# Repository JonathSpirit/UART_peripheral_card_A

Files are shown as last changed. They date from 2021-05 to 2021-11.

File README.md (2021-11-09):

# UART_peripheral_card_A

Copyright (C) 2021 Guillaume Guillet\
Licensed under CERN-OHL-W v2 or later

<table border="0px">
<tr>
<td>
This source describes Open Hardware and is licensed under the CERN-OHL-W v2 or later.
</td>
</tr>
<tr>
<td>
You may redistribute and modify this documentation and make products
using it under the terms of the CERN-OHL-W v2 (https:/cern.ch/cern-ohl).
This documentation is distributed WITHOUT ANY EXPRESS OR IMPLIED
WARRANTY, INCLUDING OF MERCHANTABILITY, SATISFACTORY QUALITY
AND FITNESS FOR A PARTICULAR PURPOSE. Please see the CERN-OHL-W v2
for applicable conditions.
</td>
</tr>
</table>

Made with [Kicad](https://kicad.org/)

## Description
A UART peripheral card compatible with [PP1 standard](https://github.com/JonathSpirit/GComputer_standard).
This is a homemade without any microcontroller UART board that can transmit and receive in fixed 9600 baud rate and full-duplex.

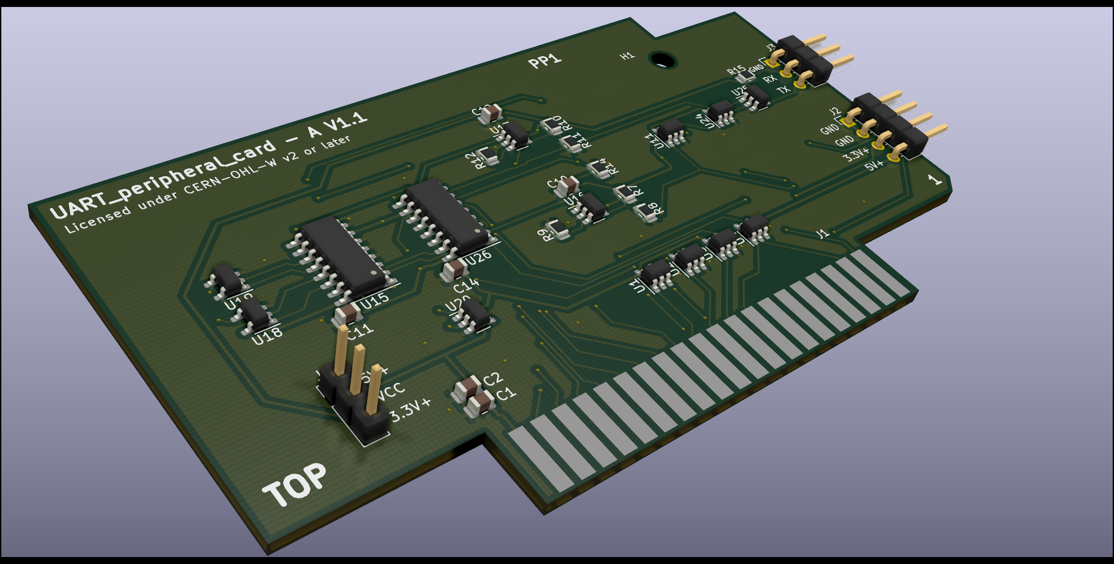
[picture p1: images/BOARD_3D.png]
BOARD_3D

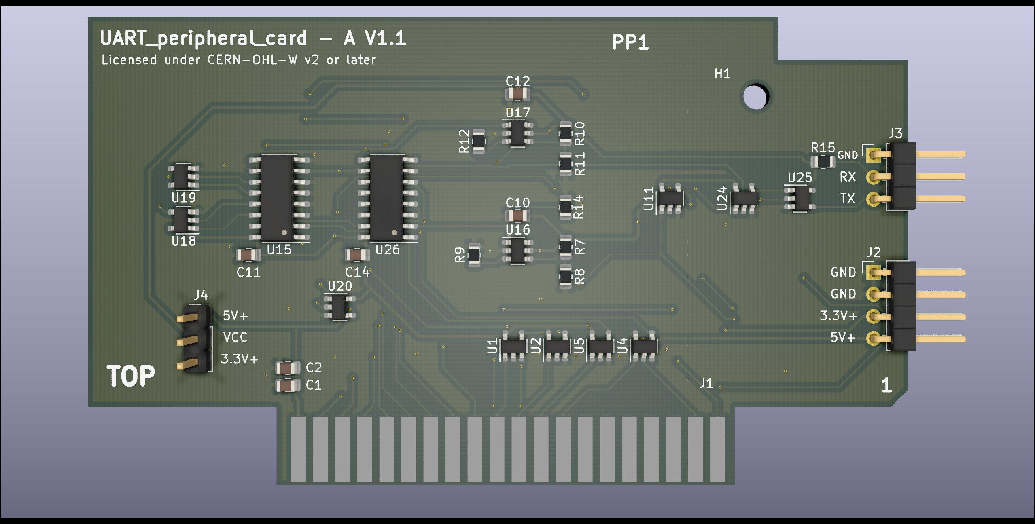
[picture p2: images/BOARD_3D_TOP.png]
BOARD_3D_TOP
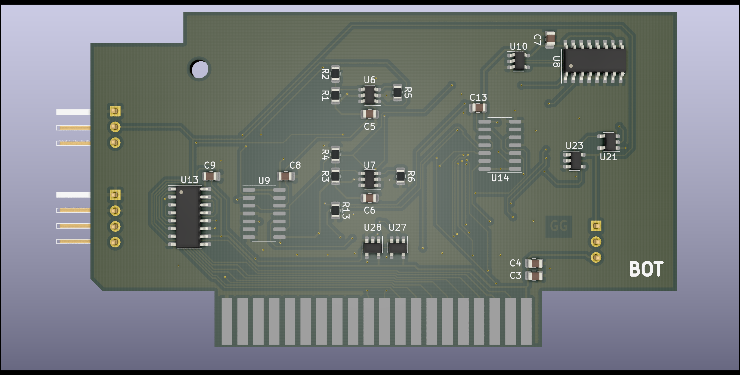
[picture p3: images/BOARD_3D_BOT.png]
BOARD_3D_BOT
 

## Stats





\
\
\


## Main features

- Follow the [PP1](https://github.com/JonathSpirit/GComputer_standard) standard.

- Fixed 9600 baud rate.

- Full duplex.

- 1 byte receive/transmit buffer.

- Compatible CMOS/TTL logic level.

## Documents
[Schematics (.pdf)](documents/UART_peripheral_card_A_schematics.pdf)

[Materials (.pdf)](documents/UART_peripheral_card_A_materials.pdf)

## Contributing / Questions
Please see [Contributing file](CONTRIBUTING.md)

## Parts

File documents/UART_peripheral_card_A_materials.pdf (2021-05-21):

1

UART_peripheral_card_A_materials.fods

UART_peripheral_card | A V1.1
Author : Guillaume Guillet | Revision 1 | Licensed under CERN-OHL-W v2 or later
Type | Value | Q | References | Package | Manufacturer | Store | Store ID | Unit price* | Price
C | 10nF | 6 | C7 to C9, C11, C13, C14 | C_0805_2012Metric | KEMET | Mouser | 80-C0805C103J5R | 0.092 | 0.552
| 1uF | 2 | C1, C3 | C_0805_2012Metric | KEMET | Mouser | 80-C0805C105K3R | 0.119 | 0.238
| 100nF | 6 | C2, C4 to C6, C10, C12 | C_0805_2012Metric | KEMET | Mouser | 80-C0805C104M3R | 0.092 | 0.552
U | LTC6990CS6 | 2 | U7, U16 | SOT-23-6 | Analog Devices | Mouser | 584-LTC6990CS6TRMPBF | 3.68 | 7.36
| LTC6994-1 | 2 | U6, U17 | SOT-23-6 | Analog Devices | Mouser | 584-C6994IS6-1TRMPBF | 3.68 | 7.36
| CD74AC161M | 2 | U8, U15 | SOP-16_3.9x9.9mm_P1.27mm | Texas Instruments | Mouser | 595-CD74AC161M | 0.751 | 1.502
| 74HCT107 | 2 | U9, U14 | SO-14_3.9x8.65mm_P1.27mm | Nexperia | Mouser | 771-HCT107D653 | 0.558 | 1.116
| 74AHC1G125 | 2 | U27, U28 | SOT-23-5 | Texas Instruments | Mouser | 595-SN74AHC1G125DBVR | 0.3 | 0.6
| 74AHC1G04 | 1 | U23 | SOT-23-5 | Texas Instruments | Mouser | 595-SN74AHC1G04DBVR | 0.274 | 0.274
| 74AHC1G08 | 1 | U24 | SOT-23-5 | Texas Instruments | Mouser | 595-SN74AHC1G08DBVR | 0.274 | 0.274
| 74AHC1G32 | 5 | U11, U18, U19, U21, U25 | SOT-23-5 | Texas Instruments | Mouser | 595-SN74AHC1G32DBVR | 0.274 | 1.37
| 74AHC1G00 | 6 | U1, U2, U4, U5, U10, U20 | SOT-23-5 | Texas Instruments | Mouser | 595-SN74AHC1G00DBVR | 0.3 | 1.8
| 74AHC595 | 1 | U13 | SOIC-16_3.9x9.9mm_P1.27mm | Texas Instruments | Mouser | 595-SN74AHC595DRE4 | 0.485 | 0.485
| 74HC165 | 1 | U26 | SOIC-16_3.9x9.9mm_P1.27mm | Texas Instruments | Mouser | 595-SN74HC165DRG4 | 0.403 | 0.403
R | 102k | 2 | R1, R11 | R_0805_2012Metric | Bourns | Mouser | 652-CR0805FX-1023ELF | 0.092 | 0.184
| 1M | 2 | R3, R7 | R_0805_2012Metric | Bourns | Mouser | 652-CR0805FX-1004ELF | 0.092 | 0.184
| 562k | 1 | R12 | R_0805_2012Metric | Bourns | Mouser | 652-CR0805FX-5623ELF | 0.092 | 0.092
| 10k | 3 | R13 to R15 | R_0805_2012Metric | Bourns | Mouser | 652-CR0805-JW-103ELF | 0.092 | 0.276
| 976k | 2 | R2, R10 | R_0805_2012Metric | Bourns | Mouser | 652-CR0805FX-9763ELF | 0.092 | 0.184
| 280k | 2 | R4, R8 | R_0805_2012Metric | Bourns | Mouser | 652-CR0805FX-2803ELF | 0.092 | 0.184
| 243k | 1 | R5 | R_0805_2012Metric | Bourns | Mouser | 652-CR0805FX-2433ELF | 0.092 | 0.092
| 649k | 2 | R6, R9 | R_0805_2012Metric | Vishay / Dale | Mouser | 71-CRCW0805649KFKEA | 0.092 | 0.184
J | Conn_01x04_Male_H | 1 | J2 | PinHeader_1x04_P2.54mm_Horizontal | TE connectivity | Mouser | 571-826947-4 | 0.384 | 0.384
| Conn_01x03_Male_H | 1 | J3 | PinHeader_1x03_P2.54mm_Horizontal | TE connectivity | Mouser | 571-826947-3 | 0.356 | 0.356
| Conn_01x03_Male_V | 1 | J4 | PinHeader_1x03_P2.54mm_Vertical | TE connectivity | Mouser | 571-4-103321-5 | 0.211 | 0.211
| Jumper | 1 | - | Jumper | Harwin | Mouser | 855-M7582-05 | 0.183 | 0.183
- | PCB_AV1.1 | 1 | - | - | G.Guillet | - | | | 0
Total price : | 26.4
*Depend of the quantity | Price is in CHF

# Project :

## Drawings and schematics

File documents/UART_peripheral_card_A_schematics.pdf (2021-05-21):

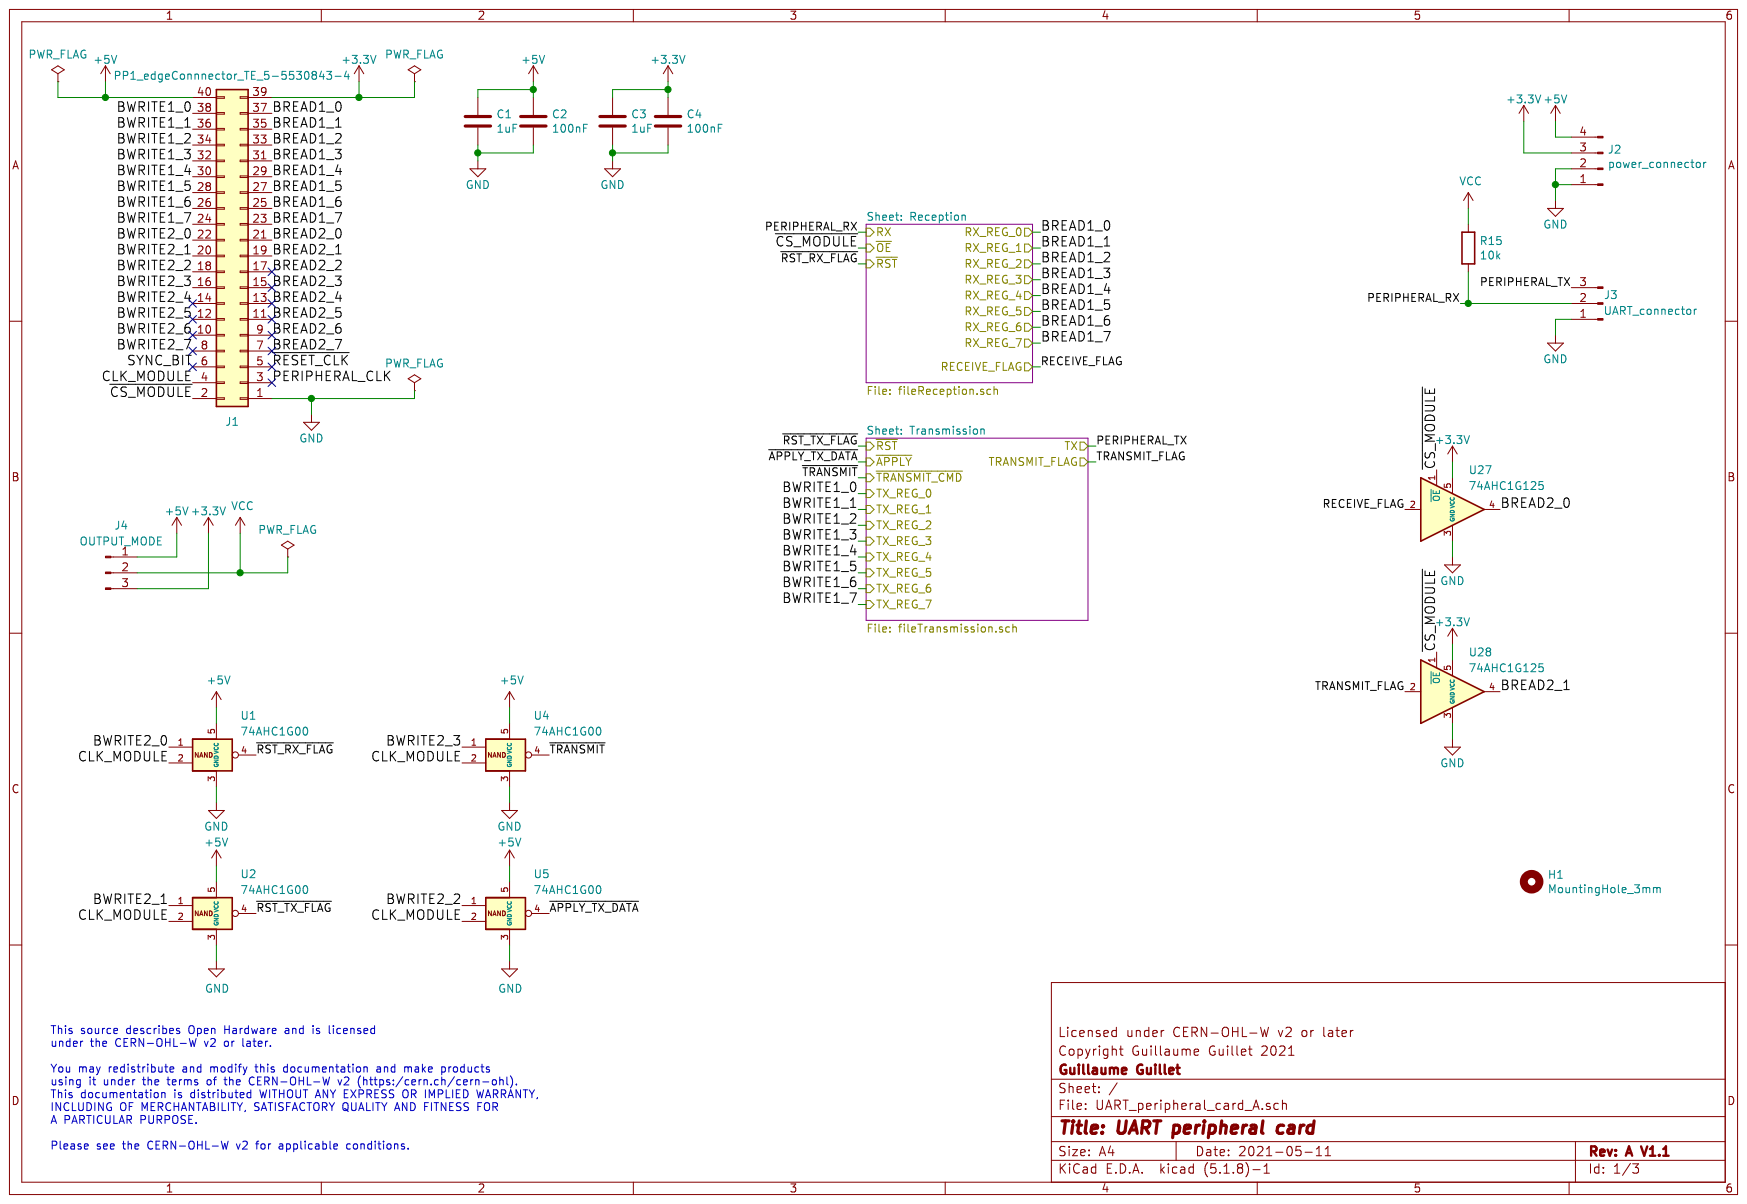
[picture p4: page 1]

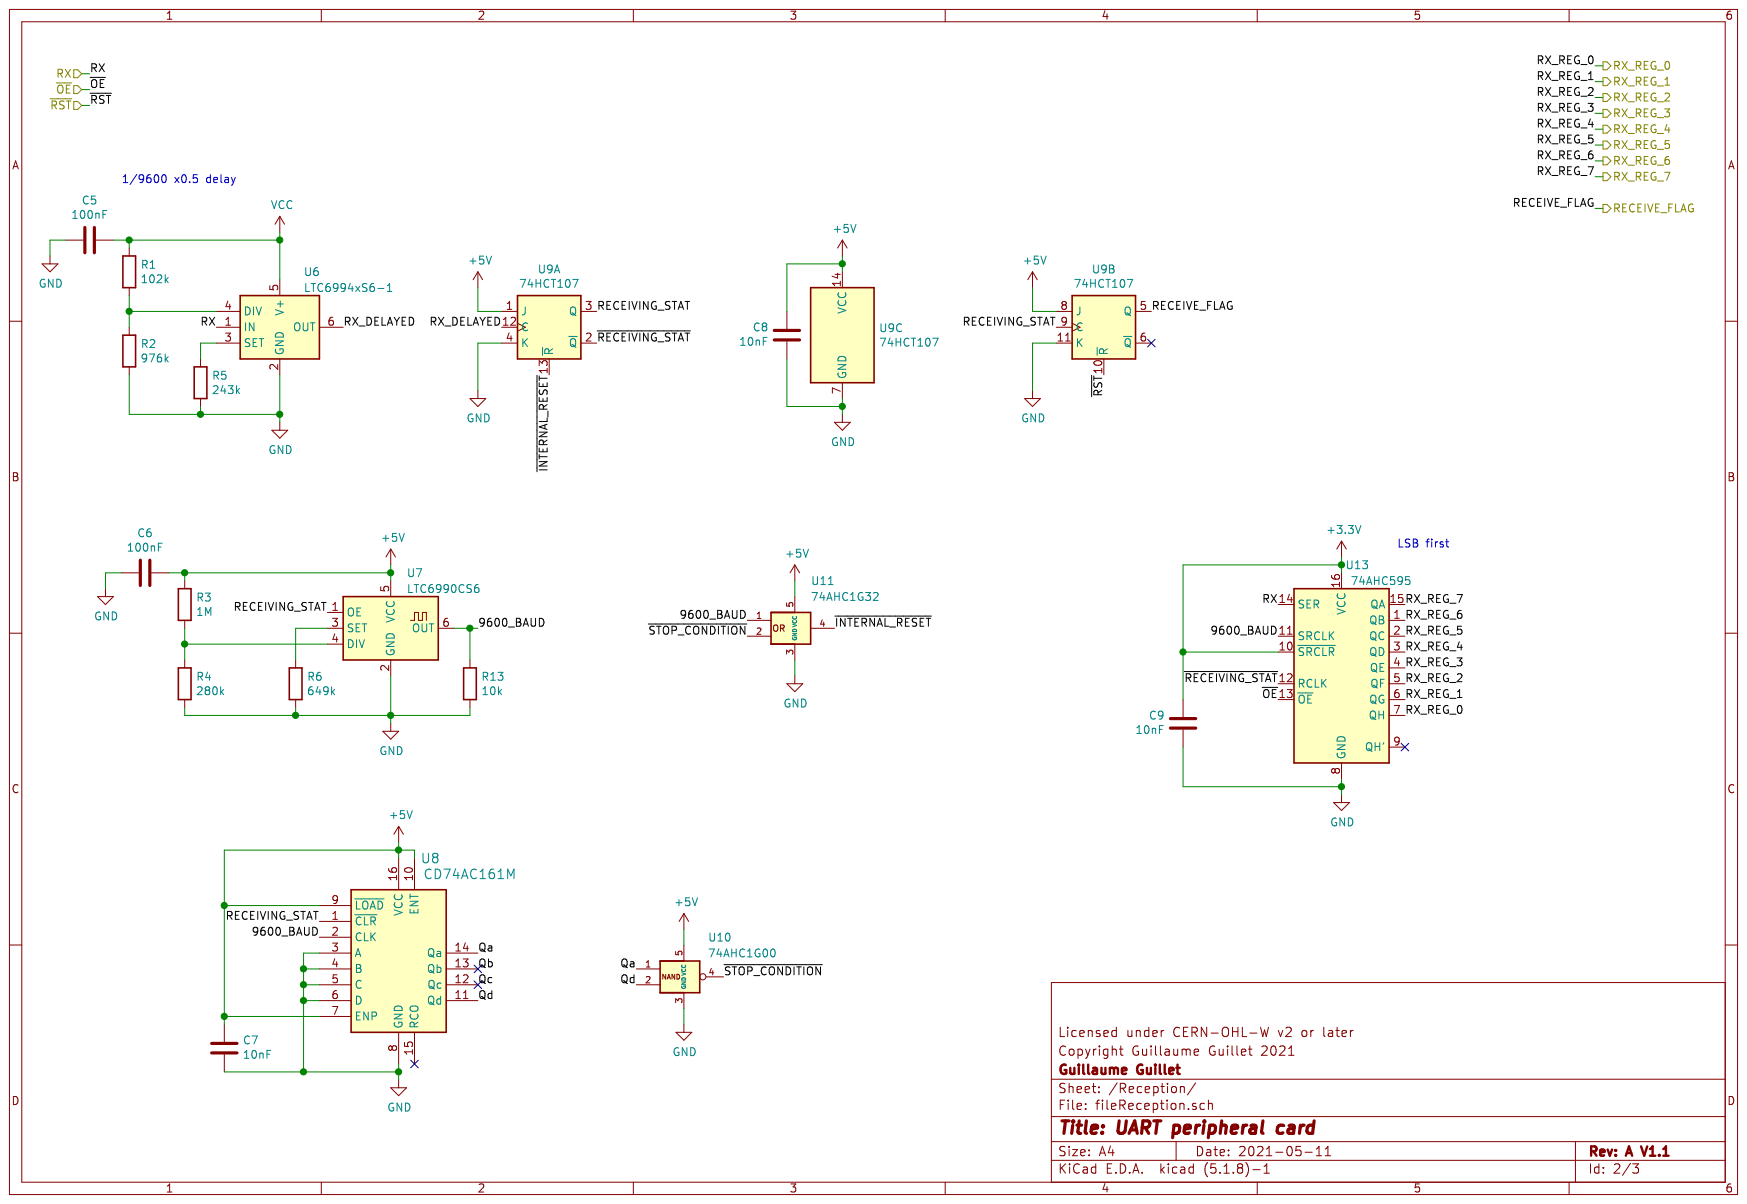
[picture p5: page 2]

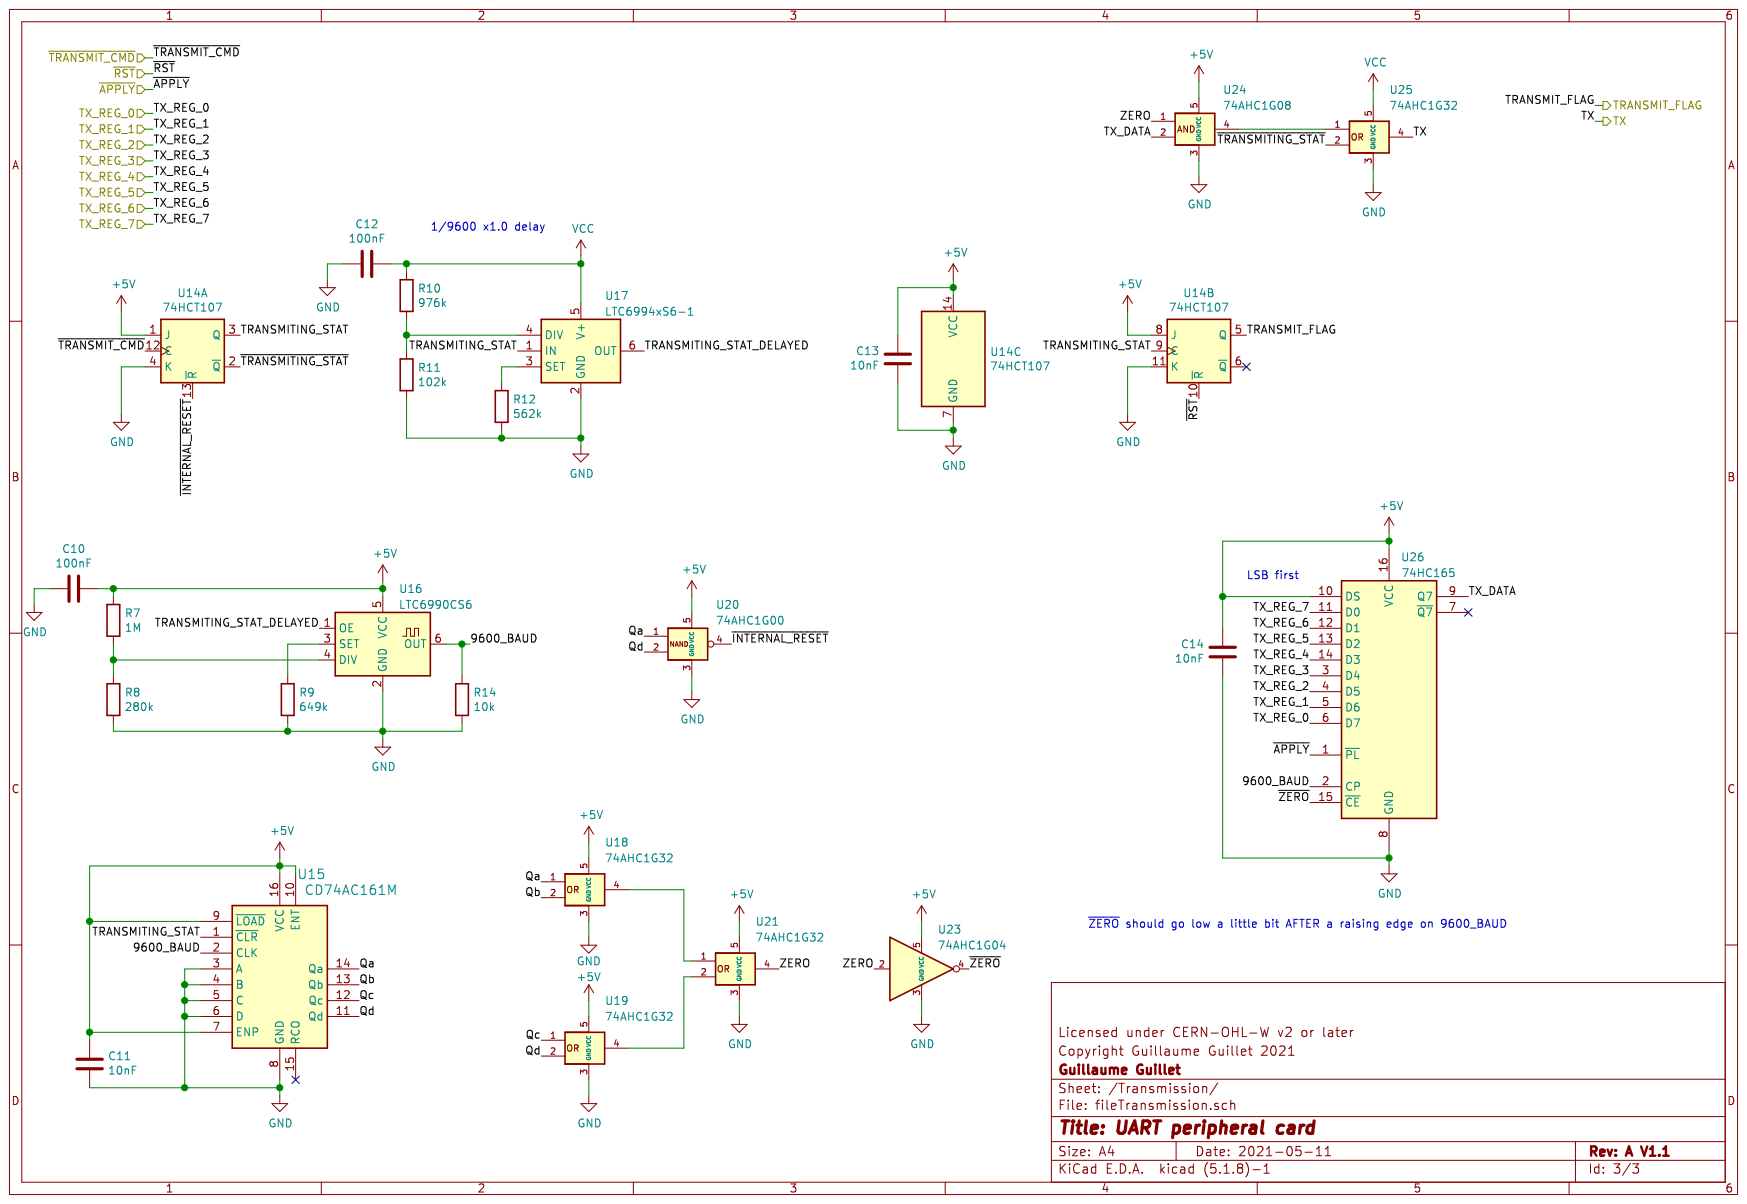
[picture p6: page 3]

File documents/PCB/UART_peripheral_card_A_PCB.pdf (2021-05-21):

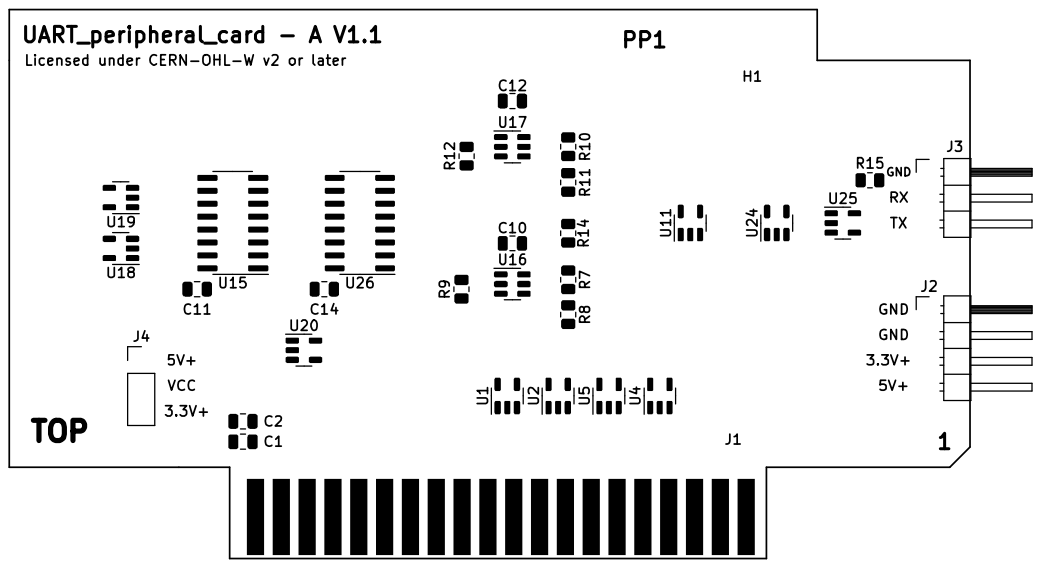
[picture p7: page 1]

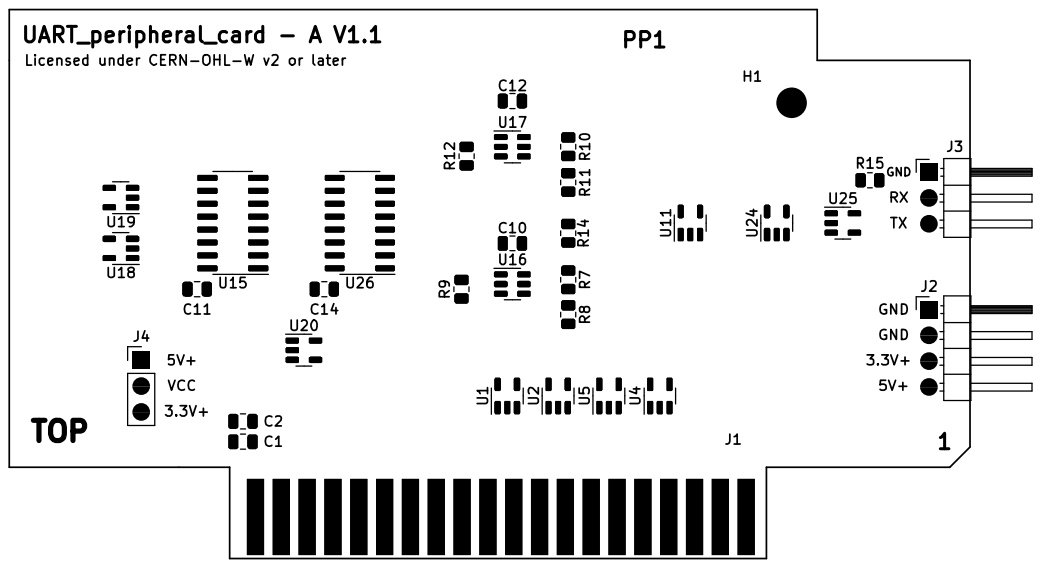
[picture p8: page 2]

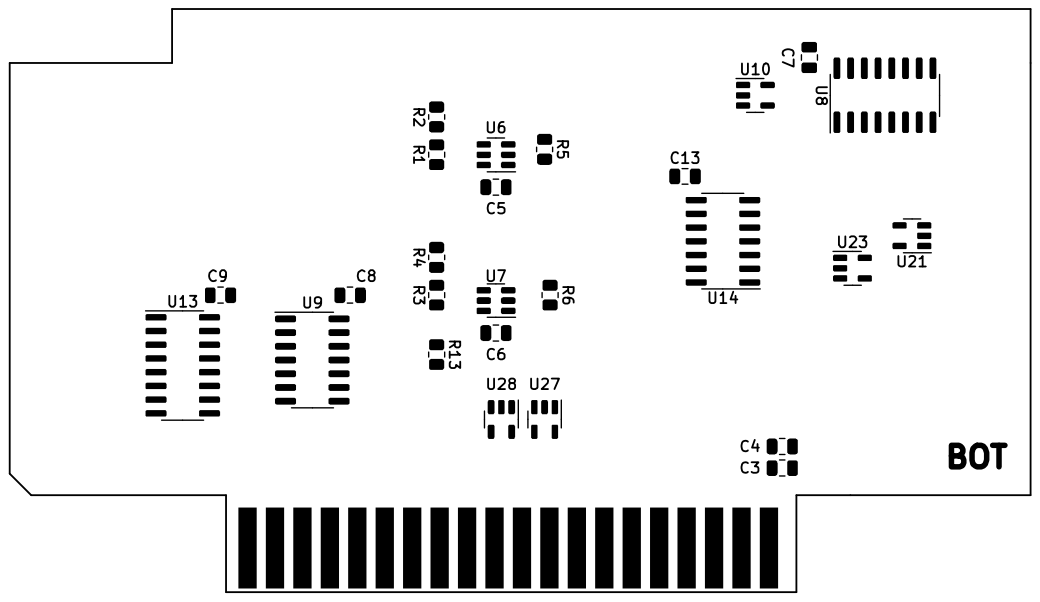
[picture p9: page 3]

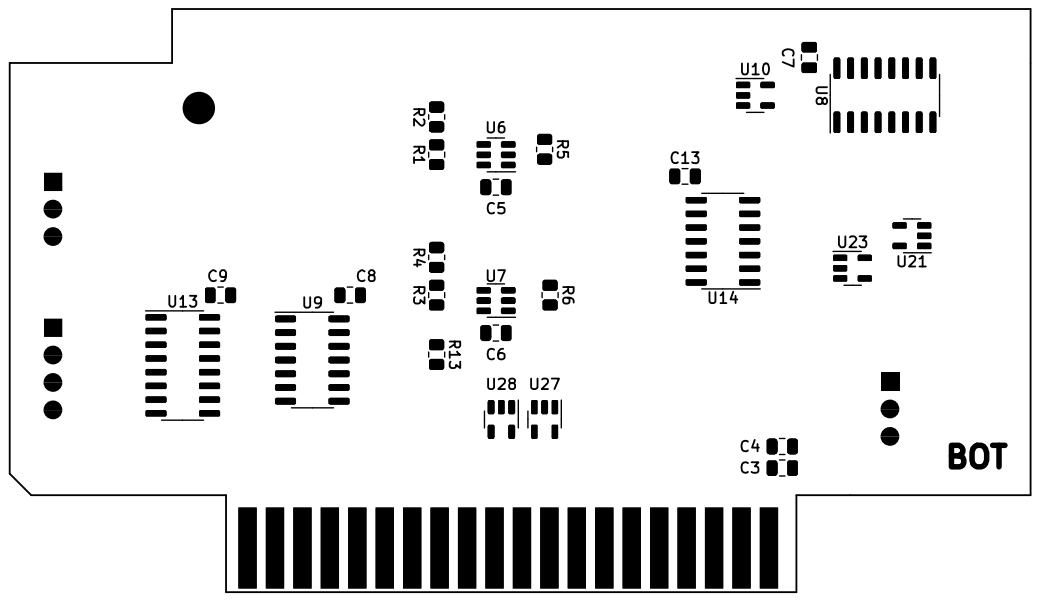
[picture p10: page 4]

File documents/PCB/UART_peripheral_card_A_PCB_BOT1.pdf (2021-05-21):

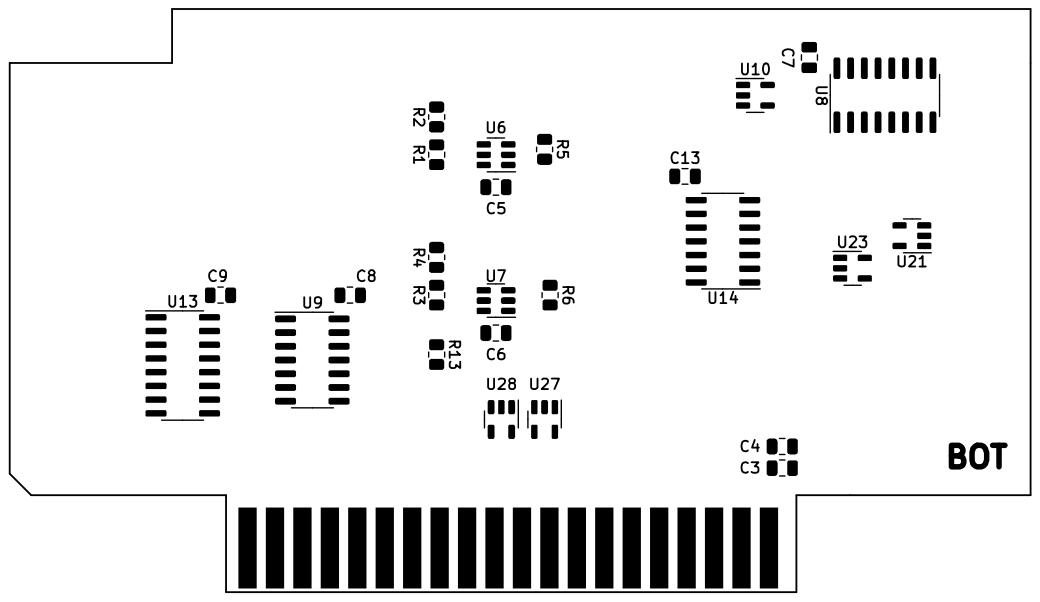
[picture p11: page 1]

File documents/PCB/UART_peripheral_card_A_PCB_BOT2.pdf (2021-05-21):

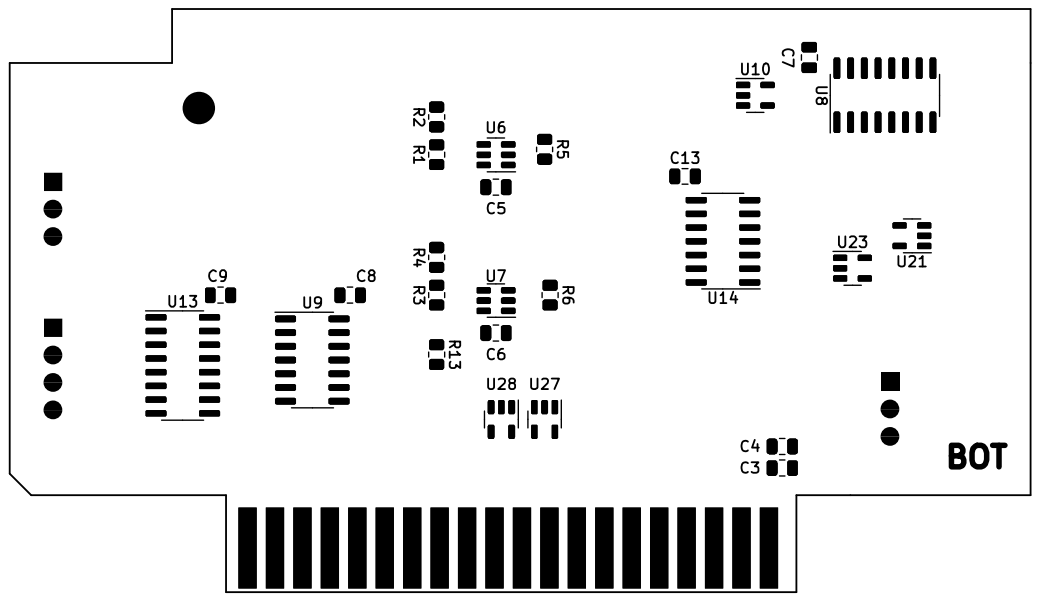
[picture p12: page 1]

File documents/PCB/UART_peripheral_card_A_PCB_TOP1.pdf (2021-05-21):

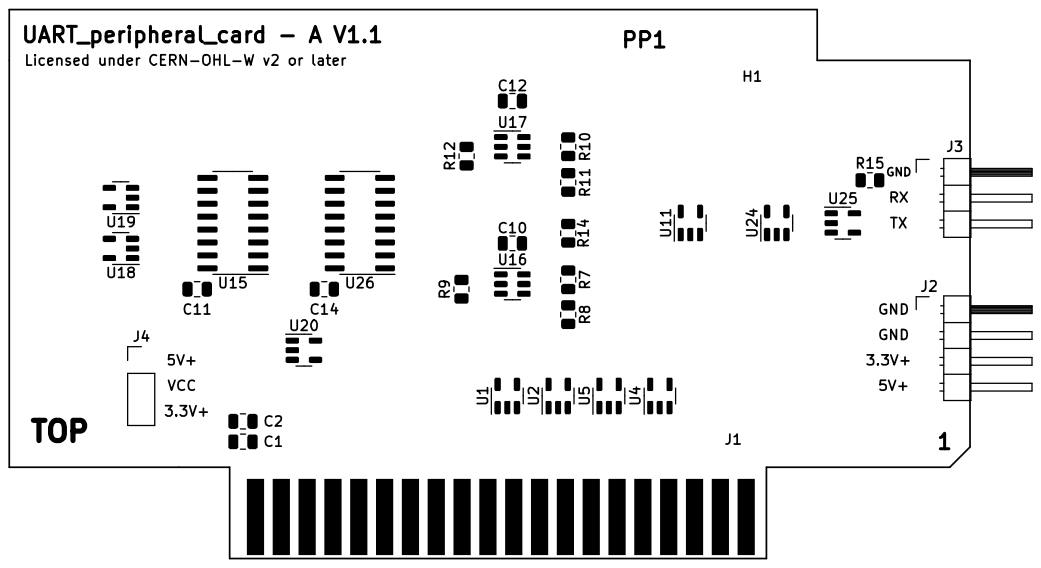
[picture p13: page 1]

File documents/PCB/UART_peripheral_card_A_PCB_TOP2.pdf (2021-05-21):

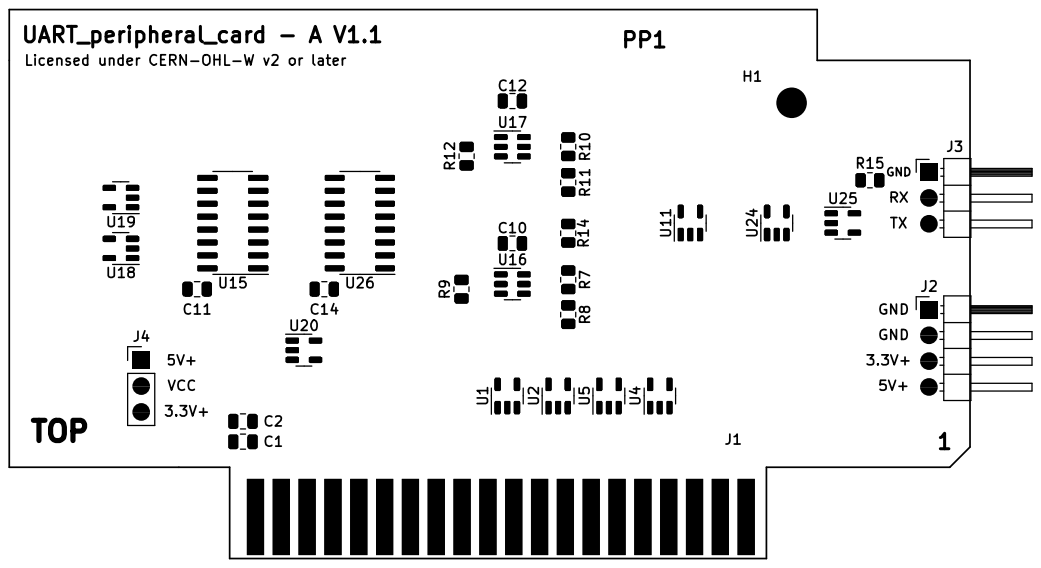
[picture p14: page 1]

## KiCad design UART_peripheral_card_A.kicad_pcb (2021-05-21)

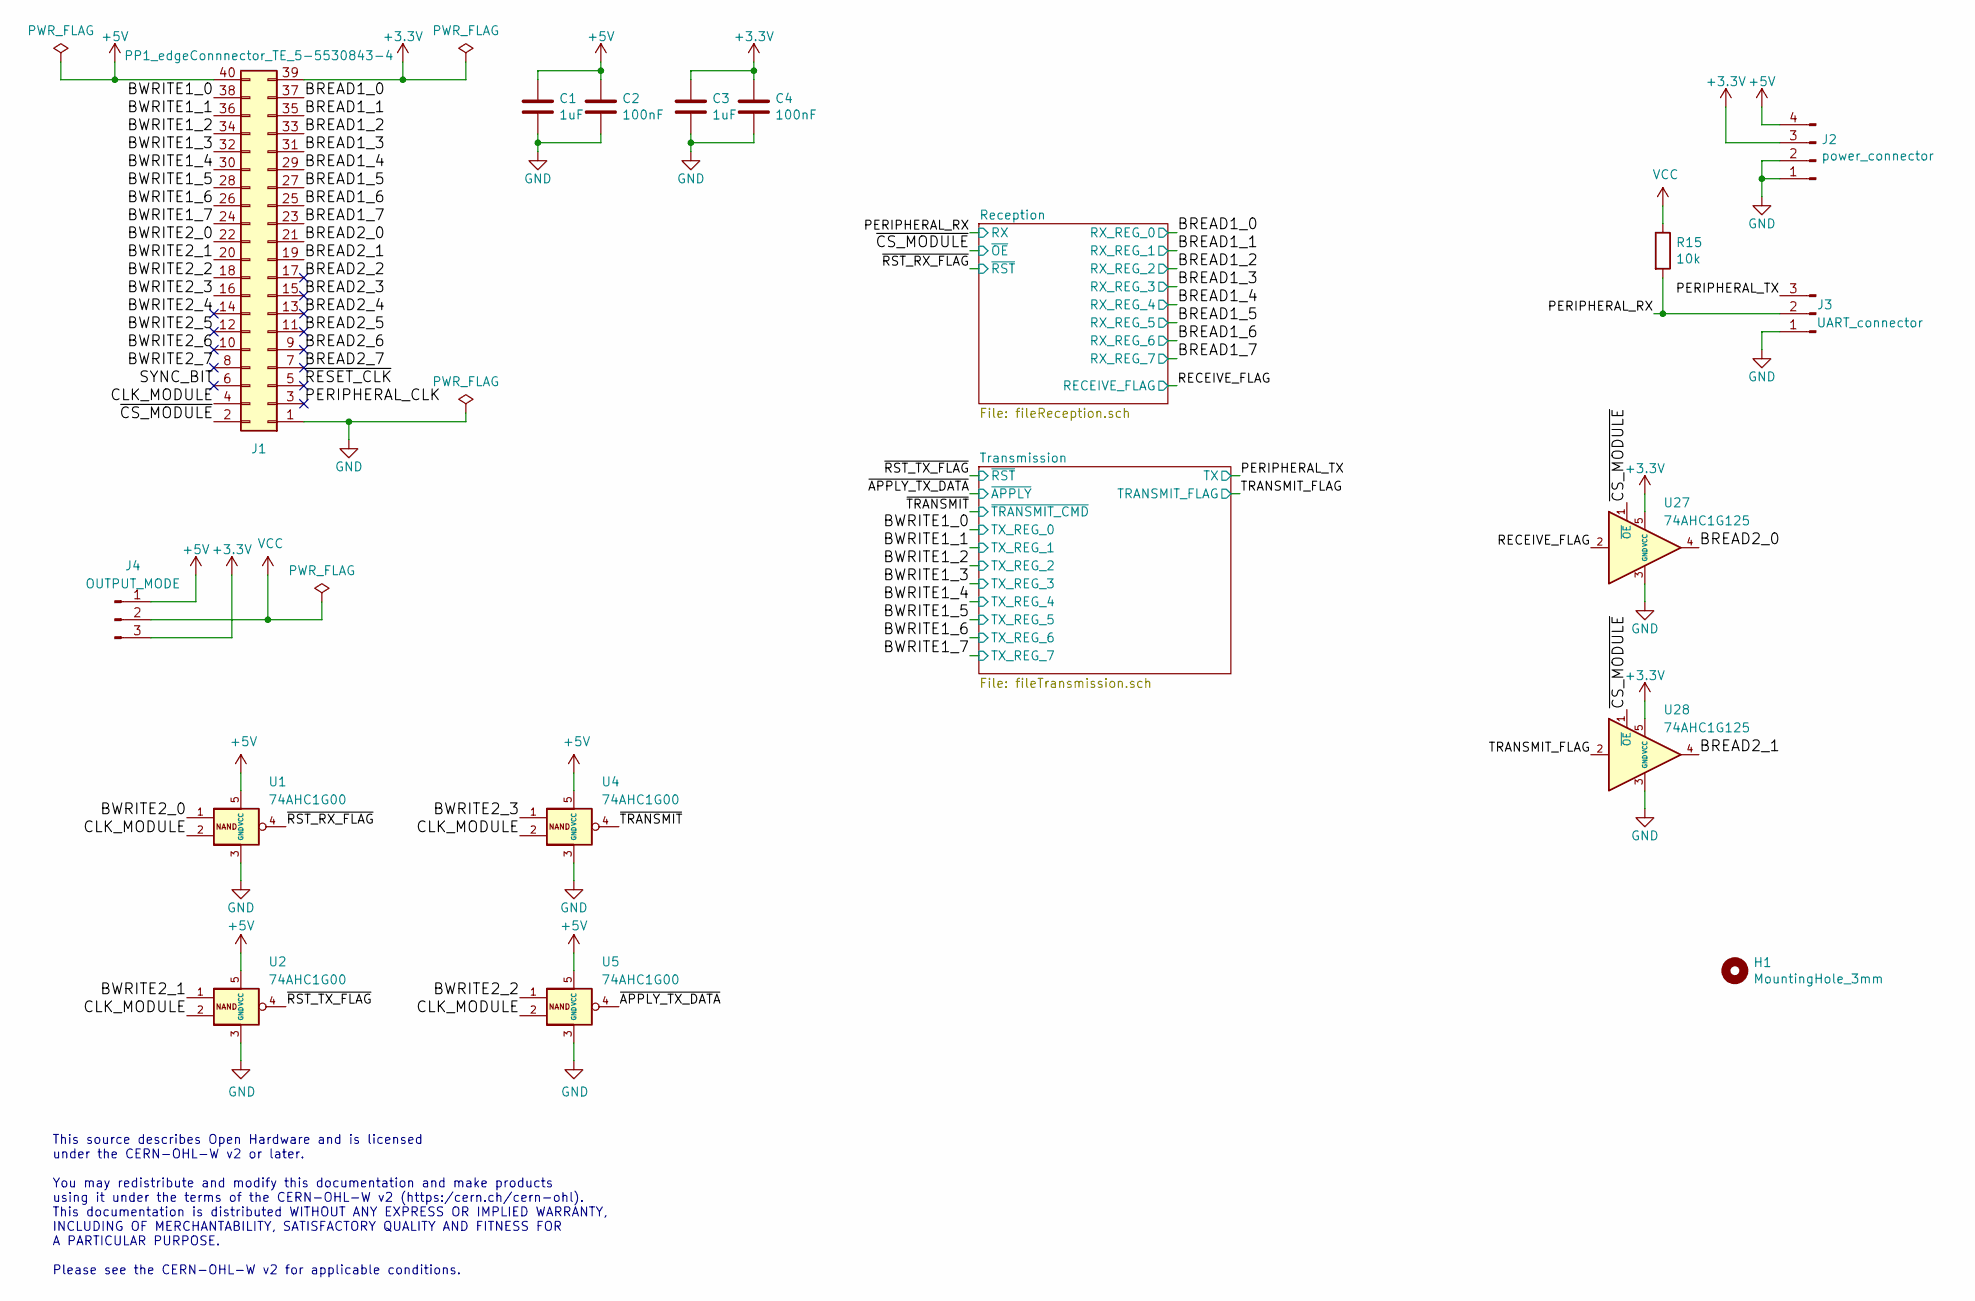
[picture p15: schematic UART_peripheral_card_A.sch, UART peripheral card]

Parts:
C1, C3: 1uF; C_0805_2012Metric
C2, C4: 100nF; C_0805_2012Metric
H1: MountingHole_3mm
J1: PP1_edgeConnnector_TE_5-5530843-4; TE_5-5530843-4_edge
J2: power_connector; PinHeader_1x04_P2.54mm_Horizontal
J3: UART_connector; PinHeader_1x03_P2.54mm_Horizontal
J4: OUTPUT_MODE; PinHeader_1x03_P2.54mm_Vertical
R15: 10k; R_0805_2012Metric
U1, U2, U4, U5: 74AHC1G00; SOT-23-5
U27, U28: 74AHC1G125; SOT-23-5

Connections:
+3V3: C3.1, C4.1, J1.39, J2.3, J4.3, U27.5 (VCC), U28.5 (VCC); also elsewhere on the board
+5V: C1.1, C2.1, J1.40, J2.4, J4.1, U1.5 (VCC), U2.5 (VCC), U4.5 (VCC), U5.5 (VCC); also elsewhere on the board
/BREAD1_0: J1.37; also elsewhere on the board
/BREAD1_1: J1.35; also elsewhere on the board
/BREAD1_2: J1.33; also elsewhere on the board
/BREAD1_3: J1.31; also elsewhere on the board
/BREAD1_4: J1.29; also elsewhere on the board
/BREAD1_5: J1.27; also elsewhere on the board
/BREAD1_6: J1.25; also elsewhere on the board
/BREAD1_7: J1.23; also elsewhere on the board
/BREAD2_0: J1.21, U27.4
/BREAD2_1: J1.19, U28.4
/BREAD2_2: J1.17
/BREAD2_3: J1.15
/BREAD2_4: J1.13
/BREAD2_5: J1.11
/BREAD2_6: J1.9
/BREAD2_7: J1.7
/BWRITE1_0: J1.38; also elsewhere on the board
/BWRITE1_1: J1.36; also elsewhere on the board
/BWRITE1_2: J1.34; also elsewhere on the board
/BWRITE1_3: J1.32; also elsewhere on the board
/BWRITE1_4: J1.30; also elsewhere on the board
/BWRITE1_5: J1.28; also elsewhere on the board
/BWRITE1_6: J1.26; also elsewhere on the board
/BWRITE1_7: J1.24; also elsewhere on the board
/BWRITE2_0: J1.22, U1.1
/BWRITE2_1: J1.20, U2.1
/BWRITE2_2: J1.18, U5.1
/BWRITE2_3: J1.16, U4.1
/BWRITE2_4: J1.14
/BWRITE2_5: J1.12
/BWRITE2_6: J1.10
/BWRITE2_7: J1.8
/CLK_MODULE: J1.4, U1.2, U2.2, U4.2, U5.2
/PERIPHERAL_CLK: J1.3
/PERIPHERAL_RX: J3.2, R15.2; also elsewhere on the board
/PERIPHERAL_TX: J3.3; also elsewhere on the board
/RECEIVE_FLAG: U27.2; also elsewhere on the board
/SYNC_BIT: J1.6
/TRANSMIT_FLAG: U28.2; also elsewhere on the board
/~APPLY_TX_DATA: U5.4; also elsewhere on the board
/~CS_MODULE: J1.2, U27.1 (~OE), U28.1 (~OE); also elsewhere on the board
/~RESET_CLK: J1.5
/~RST_RX_FLAG: U1.4; also elsewhere on the board
/~RST_TX_FLAG: U2.4; also elsewhere on the board
/~TRANSMIT: U4.4; also elsewhere on the board
GND: C1.2, C2.2, C3.2, C4.2, J1.1, J2.1, J2.2, J3.1, U1.3 (GND), U2.3 (GND), U4.3 (GND), U5.3 (GND), U27.3 (GND), U28.3 (GND); also elsewhere on the board
VCC: J4.2, R15.1; also elsewhere on the board

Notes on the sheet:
This source describes Open Hardware and is licensed under the CERN-OHL-W v2 or later. You may redistribute and modify this documentation and make products using it under the terms of the CERN-OHL-W v2 (https:/cern.ch/cern-ohl). This documentation is distributed WITHOUT ANY EXPRESS OR IMPLIED WARRAN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

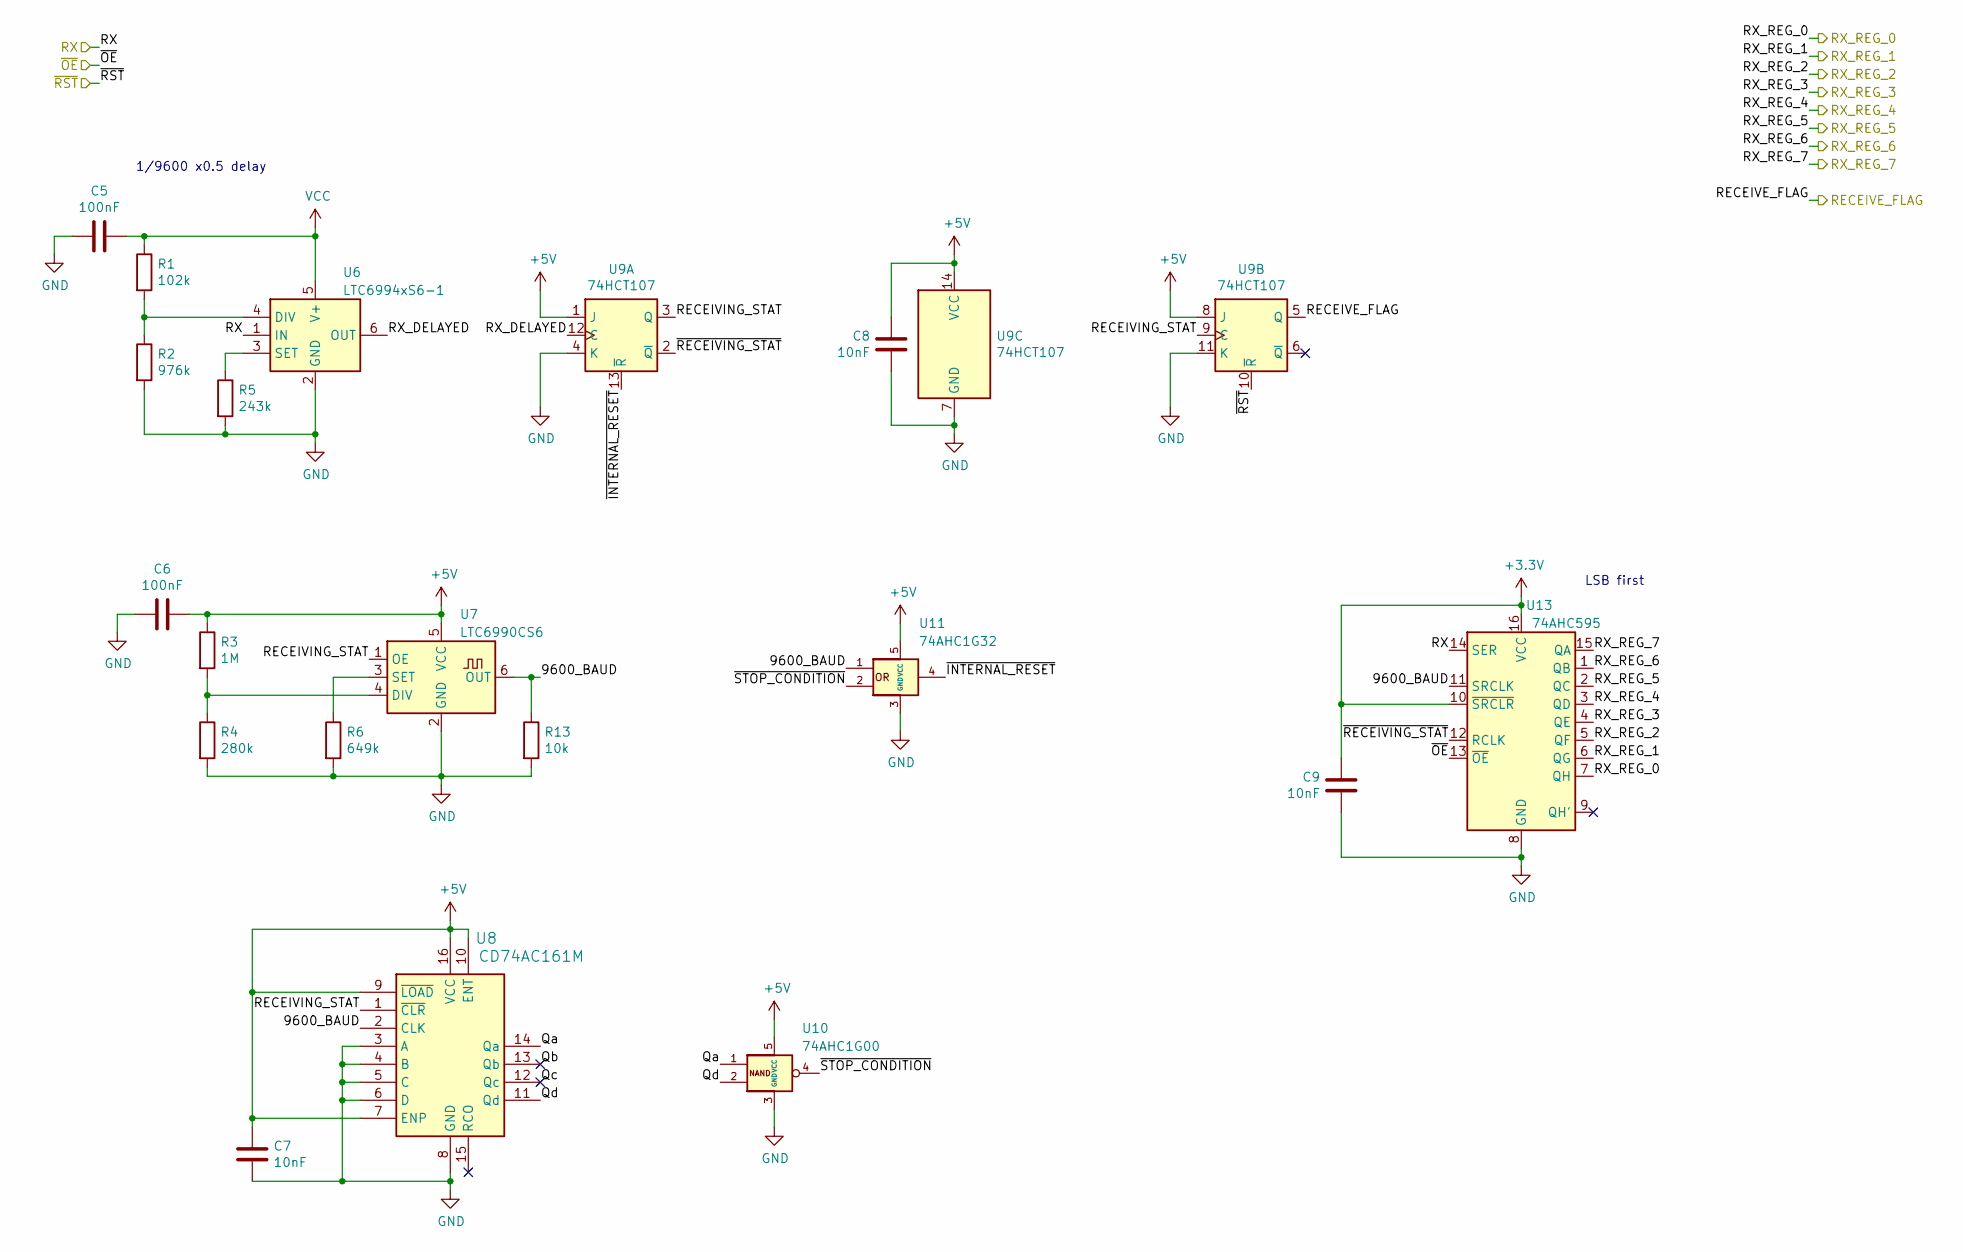
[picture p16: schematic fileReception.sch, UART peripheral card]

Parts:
C5, C6: 100nF; C_0805_2012Metric
C7, C8, C9: 10nF; C_0805_2012Metric
R1: 102k; R_0805_2012Metric
R2: 976k; R_0805_2012Metric
R3: 1M; R_0805_2012Metric
R4: 280k; R_0805_2012Metric
R5: 243k; R_0805_2012Metric
R6: 649k; R_0805_2012Metric
R13: 10k; R_0805_2012Metric
U6: LTC6994xS6-1; SOT-23-6
U7: LTC6990CS6; SOT-23-6
U8: CD74AC161M; SOP-16_3.9x9.9mm_P1.27mm
U9: 74HCT107; SO-14_3.9x8.65mm_P1.27mm
U10: 74AHC1G00; SOT-23-5
U11: 74AHC1G32; SOT-23-5
U13: 74AHC595; SOIC-16_3.9x9.9mm_P1.27mm

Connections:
+3V3: C9.2, U13.10 (~SRCLR), U13.16 (VCC); also elsewhere on the board
+5V: C6.1, C7.2, C8.2, R3.1, U7.5 (VCC), U8.7 (ENP), U8.9 (~LOAD), U8.10 (ENT), U8.16 (VCC), U9.1 (J), U9.8 (J), U9.14 (VCC), U10.5 (VCC), U11.5 (VCC); also elsewhere on the board
/BREAD1_0: U13.7 (QH); also elsewhere on the board
/BREAD1_1: U13.6 (QG); also elsewhere on the board
/BREAD1_2: U13.5 (QF); also elsewhere on the board
/BREAD1_3: U13.4 (QE); also elsewhere on the board
/BREAD1_4: U13.3 (QD); also elsewhere on the board
/BREAD1_5: U13.2 (QC); also elsewhere on the board
/BREAD1_6: U13.1 (QB); also elsewhere on the board
/BREAD1_7: U13.15 (QA); also elsewhere on the board
/PERIPHERAL_RX: U6.1 (IN), U13.14 (SER); also elsewhere on the board
/RECEIVE_FLAG: U9.5 (Q); also elsewhere on the board
/Reception/9600_BAUD: R13.1, U7.6 (OUT), U8.2 (CLK), U11.1, U13.11 (SRCLK)
/Reception/Qa: U8.14 (Qa), U10.1
/Reception/Qb: U8.13 (Qb)
/Reception/Qc: U8.12 (Qc)
/Reception/Qd: U8.11 (Qd), U10.2
/Reception/RECEIVING_STAT: U7.1 (OE), U8.1 (~CLR), U9.3 (Q), U9.9 (C)
/Reception/RX_DELAYED: U6.6 (OUT), U9.12 (C)
/Reception/~INTERNAL_RESET: U9.13 (~R), U11.4
/Reception/~RECEIVING_STAT: U9.2 (~Q), U13.12 (RCLK)
/Reception/~STOP_CONDITION: U10.4, U11.2
/~CS_MODULE: U13.13 (~OE); also elsewhere on the board
/~RST_RX_FLAG: U9.10 (~R); also elsewhere on the board
GND: C5.2, C6.2, C7.1, C8.1, C9.1, R2.2, R4.2, R5.2, R6.2, R13.2, U6.2 (GND), U7.2 (GND), U8.3 (A), U8.4 (B), U8.5 (C), U8.6 (D), U8.8 (GND), U9.4 (K), U9.7 (GND), U9.11 (K), U10.3 (GND), U11.3 (GND), U13.8 (GND); also elsewhere on the board
unnamed: R1.2, R2.1, U6.4 (DIV)
unnamed: R3.2, R4.1, U7.4 (DIV)
unnamed: R5.1, U6.3 (SET)
unnamed: R6.1, U7.3 (SET)
VCC: C5.1, R1.1, U6.5 (V+); also elsewhere on the board

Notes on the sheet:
1/9600 x0.5 delay
LSB first

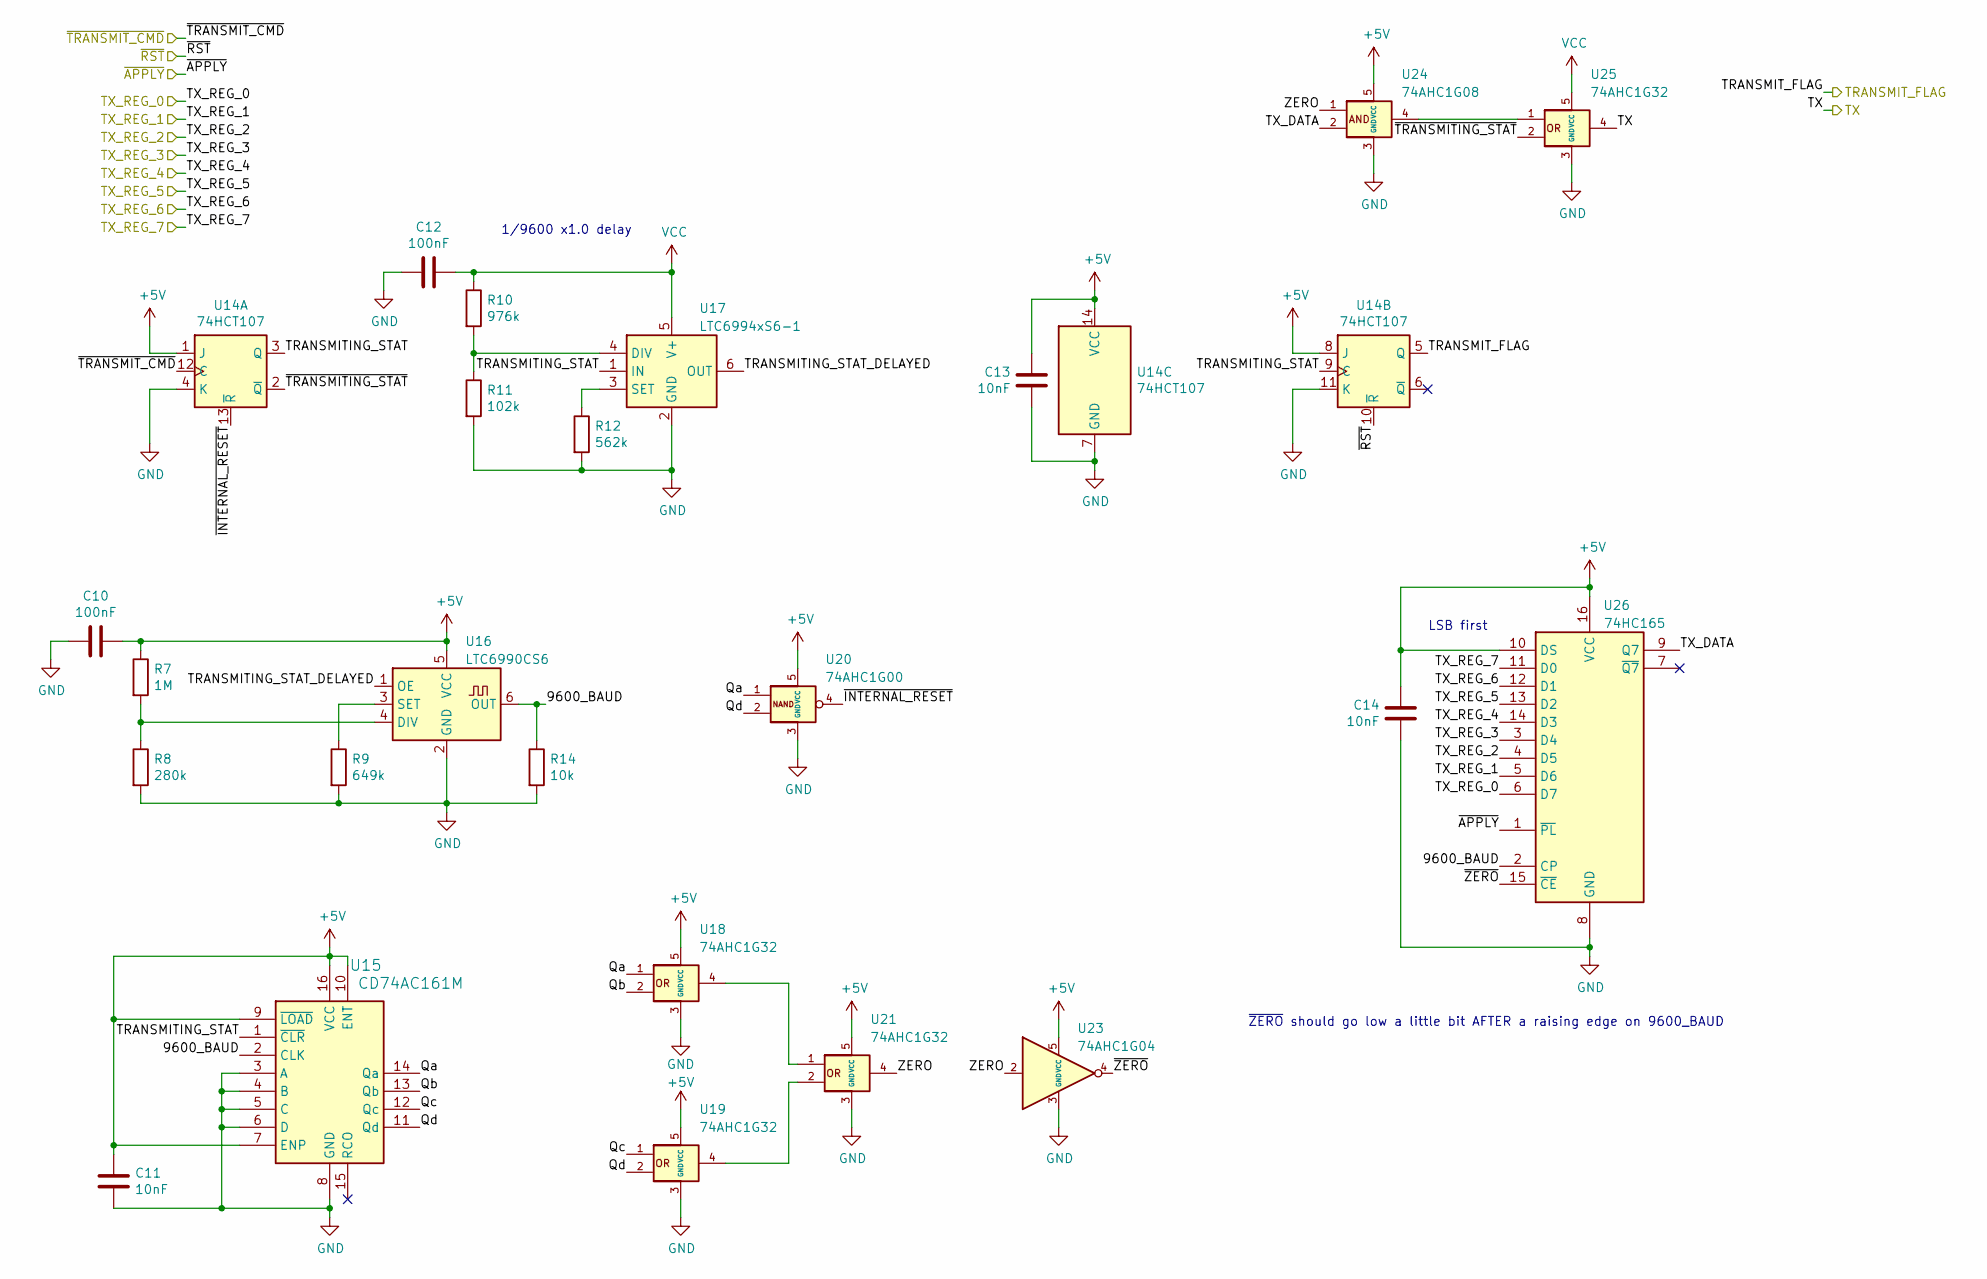
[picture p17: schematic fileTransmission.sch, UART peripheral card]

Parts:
C10, C12: 100nF; C_0805_2012Metric
C11, C13, C14: 10nF; C_0805_2012Metric
R7: 1M; R_0805_2012Metric
R8: 280k; R_0805_2012Metric
R9: 649k; R_0805_2012Metric
R10: 976k; R_0805_2012Metric
R11: 102k; R_0805_2012Metric
R12: 562k; R_0805_2012Metric
R14: 10k; R_0805_2012Metric
U14: 74HCT107; SO-14_3.9x8.65mm_P1.27mm
U15: CD74AC161M; SOP-16_3.9x9.9mm_P1.27mm
U16: LTC6990CS6; SOT-23-6
U17: LTC6994xS6-1; SOT-23-6
U18, U19, U21, U25: 74AHC1G32; SOT-23-5
U20: 74AHC1G00; SOT-23-5
U23: 74AHC1G04; SOT-23-5
U24: 74AHC1G08; SOT-23-5
U26: 74HC165; SOIC-16_3.9x9.9mm_P1.27mm

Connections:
+5V: C10.1, C11.2, C13.2, C14.2, R7.1, U14.1 (J), U14.8 (J), U14.14 (VCC), U15.7 (ENP), U15.9 (~LOAD), U15.10 (ENT), U15.16 (VCC), U16.5 (VCC), U18.5 (VCC), U19.5 (VCC), U20.5 (VCC), U21.5 (VCC), U23.5 (VCC), U24.5 (VCC), U26.10 (DS), U26.16 (VCC); also elsewhere on the board
/BWRITE1_0: U26.6 (D7); also elsewhere on the board
/BWRITE1_1: U26.5 (D6); also elsewhere on the board
/BWRITE1_2: U26.4 (D5); also elsewhere on the board
/BWRITE1_3: U26.3 (D4); also elsewhere on the board
/BWRITE1_4: U26.14 (D3); also elsewhere on the board
/BWRITE1_5: U26.13 (D2); also elsewhere on the board
/BWRITE1_6: U26.12 (D1); also elsewhere on the board
/BWRITE1_7: U26.11 (D0); also elsewhere on the board
/PERIPHERAL_TX: U25.4; also elsewhere on the board
/TRANSMIT_FLAG: U14.5 (Q); also elsewhere on the board
/Transmission/9600_BAUD: R14.1, U15.2 (CLK), U16.6 (OUT), U26.2 (CP)
/Transmission/Qa: U15.14 (Qa), U18.1, U20.1
/Transmission/Qb: U15.13 (Qb), U18.2
/Transmission/Qc: U15.12 (Qc), U19.1
/Transmission/Qd: U15.11 (Qd), U19.2, U20.2
/Transmission/TRANSMITING_STAT: U14.3 (Q), U14.9 (C), U15.1 (~CLR), U17.1 (IN)
/Transmission/TRANSMITING_STAT_DELAYED: U16.1 (OE), U17.6 (OUT)
/Transmission/TX_DATA: U24.2, U26.9 (Q7)
/Transmission/ZERO: U21.4, U23.2, U24.1
/Transmission/~INTERNAL_RESET: U14.13 (~R), U20.4
/Transmission/~TRANSMITING_STAT: U14.2 (~Q), U25.2
/Transmission/~ZERO: U23.4, U26.15 (~CE)
/~APPLY_TX_DATA: U26.1 (~PL); also elsewhere on the board
/~RST_TX_FLAG: U14.10 (~R); also elsewhere on the board
/~TRANSMIT: U14.12 (C); also elsewhere on the board
GND: C10.2, C11.1, C12.2, C13.1, C14.1, R8.2, R9.2, R11.2, R12.2, R14.2, U14.4 (K), U14.7 (GND), U14.11 (K), U15.3 (A), U15.4 (B), U15.5 (C), U15.6 (D), U15.8 (GND), U16.2 (GND), U17.2 (GND), U18.3 (GND), U19.3 (GND), U20.3 (GND), U21.3 (GND), U23.3 (GND), U24.3 (GND), U25.3 (GND), U26.8 (GND); also elsewhere on the board
unnamed: R7.2, R8.1, U16.4 (DIV)
unnamed: R9.1, U16.3 (SET)
unnamed: R10.2, R11.1, U17.4 (DIV)
unnamed: R12.1, U17.3 (SET)
unnamed: U18.4, U21.1
unnamed: U19.4, U21.2
unnamed: U24.4, U25.1
VCC: C12.1, R10.1, U17.5 (V+), U25.5 (VCC); also elsewhere on the board

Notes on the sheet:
1/9600 x1.0 delay
~ZERO~ should go low a little bit AFTER a raising edge on 9600_BAUD
LSB first

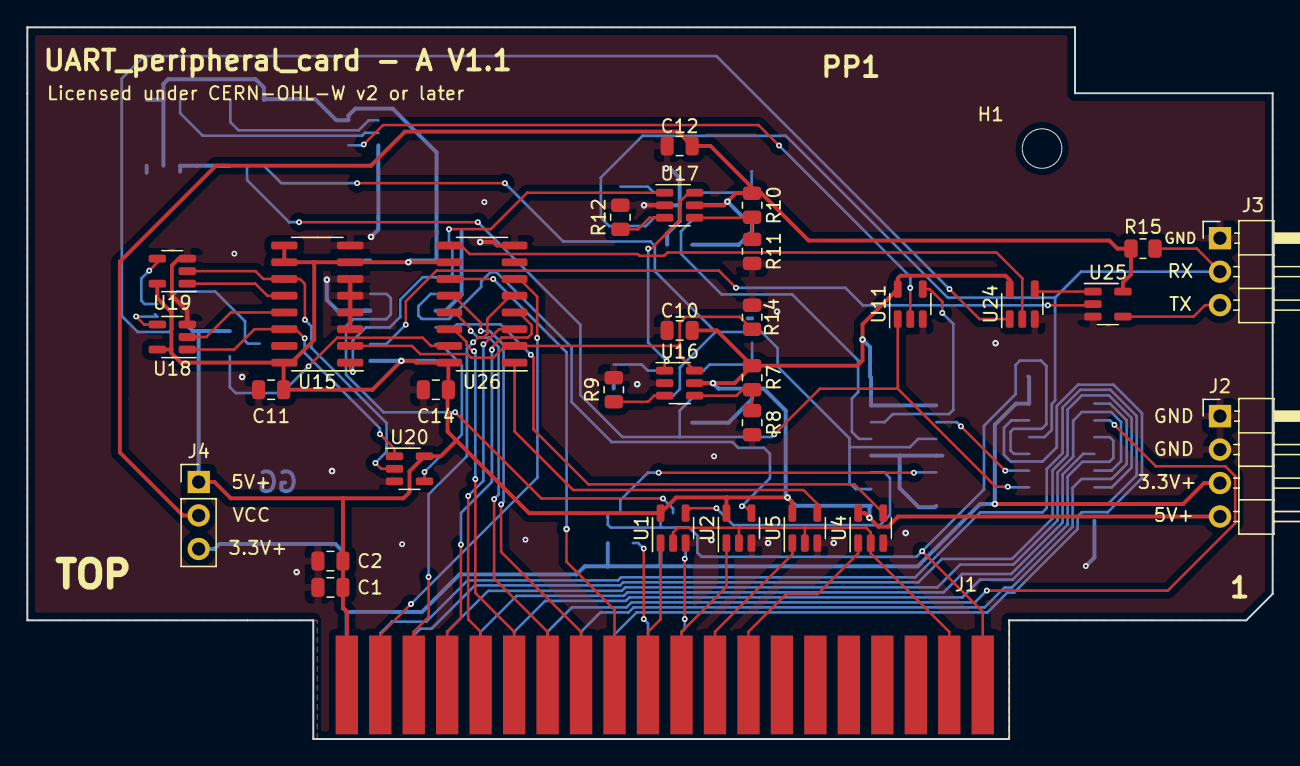
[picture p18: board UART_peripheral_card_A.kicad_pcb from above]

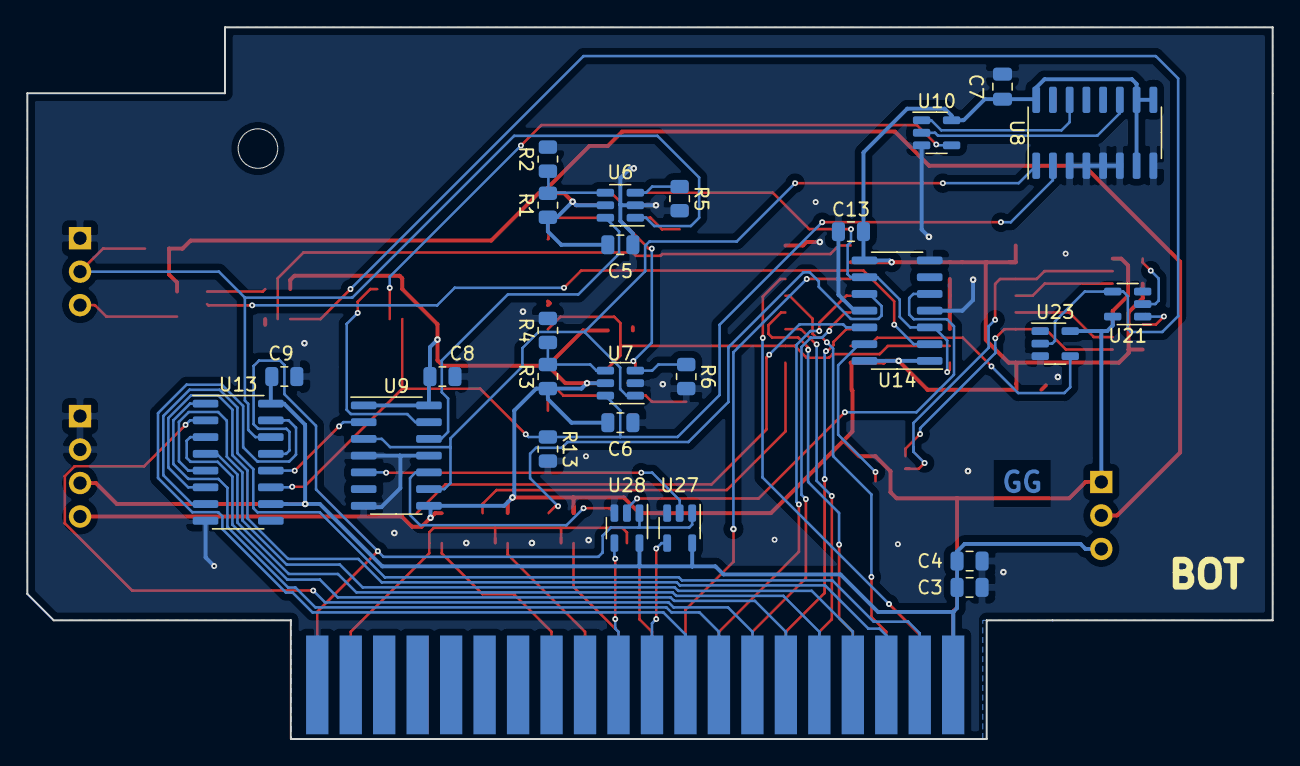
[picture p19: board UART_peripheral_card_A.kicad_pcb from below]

Board: 2 copper layers, 94.5 x 54.0 mm, 59 parts (26 on the bottom side), 67 nets.

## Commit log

2021-02-22 Initial push
    [UART_peripheral_card_A.kicad_pcb, UART_peripheral_card_A.sch, fileReception.sch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]
2021-02-24 Finish pcb routing
    [UART_peripheral_card_A-B_Cu.gbr, UART_peripheral_card_A-B_Mask.gbr, UART_peripheral_card_A-B_SilkS.gbr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]
2021-05-11 Fixing LSB first issue #1
    [fileReception.sch, fileTransmission.sch]
2021-05-11 Fix active high enable pin #2 by replacing 74AHC1G126 with 74AHC1G125
    [UART_peripheral_card_A.sch]
2021-05-11 Removing the need of U3 inverter #3 replacing U1,U2,U4,U5 with 74AHC1G00
    [UART_peripheral_card_A.sch]
2021-05-11 Adding pull-up on RX pin #4
    [UART_peripheral_card_A.sch]
2021-05-11 Optimize gates count by replacing AND,INV with NAND
    [fileReception.sch, fileTransmission.sch]
2021-05-11 Set date and version (schematics)
    [UART_peripheral_card_A.sch, fileReception.sch, fileTransmission.sch]
2021-05-11 netlist, association, CHANGELOG
    [UART_peripheral_card_A.sch, fileReception.sch, fileTransmission.sch]
2021-05-13 BOM V1.1
2021-05-19 Modify trackWidth,via diameter, first PCB 1.1 pass
    [UART_peripheral_card_A.kicad_pcb]
2021-05-20 Exporting new BOM, schematics in pdf
2021-05-20 Exporting new PCB*.pdf
2021-05-20 Exporting new fabrication files
    [UART_peripheral_card_A-B_Cu.gbr, UART_peripheral_card_A-B_Mask.gbr, UART_peripheral_card_A-B_SilkS.gbr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]

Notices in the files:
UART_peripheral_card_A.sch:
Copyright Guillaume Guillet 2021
